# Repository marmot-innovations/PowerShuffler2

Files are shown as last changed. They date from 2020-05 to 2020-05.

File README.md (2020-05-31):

# PowerShuffler2
Summary: PowerShuffler2 is an update and modification of PowerShuffler1 to handle dual battery charging by intelligently multiplexing between two outputs.

Theory of operation: In a battery stack with 99 lithium-ion cells in series, there might be more than 1 weak cells that limit the usability of the entire battery pack. Let's assume the 99 li-ion cells are arranged in groups of 9 and there are certain groups that contain cells which are stronger than others. PowerShuffler2 is a PCBA that will piggy-back on top of the existing BMS that comes with the battery pack and draw power from the stronger group in order to charge up the 1 or 2 weak cells wherever they sit in the series of 99 cells. PowerShuffler2 has built-in intelligence to select the lower of the two output cell voltages and to prevent over-discharging the stronger group by measuring the voltage of the weakest cell as it rises, and comparing it to 1/9th of the stronger group's total voltage as it falls to within a certain threshold. Pre-programmed hysteresis and voltage-read-before-charging prevents excessive start-stop charging as the cells are put through normal usage during the time when the existing BMS kicks in. Although intrusive, PowerShuffler2 is meant to be a diagnostics tool to verify and characterize weak cells within a battery stack on top of a pre-existing BMS. It does not replace the need for servicing the battery pack or using a better BMS down the road. PowerShuffler2 has no wired or wireless communication, which is not accessible anyway if piggy-backed within a battery pack enclosure.

Included in this project are:
1. Firmware for client MCU
2. PCB design for PCBA

Not included in this project is:
1. Firmware for master MCU (see PowerShuffler1 project)

Read the individual README for further details. Pictures will be added later to provide instructions for programming and installation, as well as board modifications where needed. Test data will be provided eventually.

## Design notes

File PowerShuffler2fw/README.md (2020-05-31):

These projects were created and compiled in Microchip's Atmel Studio 7.0.2397  
For the ATTINY10 SOT-23-6 microcontroller

See PowerShuffler1 project for master MCU firmware.

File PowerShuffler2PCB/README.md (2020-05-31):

## PowerShuffler 2.0 PCB design schematic, layout, Gerbers, and BOM  
KiCAD 5.0.0 for PCB design  
Microsoft Excel web for BOM  
No 3D model  
No XY pick and place Centroid  
No ODB++  
No footprint library  
No schematic library

Design bugs and comments:  
1. To program master MCU, remove R6 and C7 first, then replace them once programming is completed. These components will put too much load on ISP TPI programmer.
2. To program client MCU, remove C24 and R22 first, then replace them once completed. These components will put too much load on ISP TPI programmer.
3. J2 and J4 do not need soldered headers for programming. Just shove a 5-pin 0.1" straight strip header into it to establish electrical contact. Look up "sneaky footprints PCB" on the web.
4. Mounting holes are for 4-40 screws and stand-offs.
5. Peak 82% efficiency during max charge rate as measured.
6. Less than 0.5mA current draw from input when idle, not charging.
7. There is no D2 LED, only D1 and D3.

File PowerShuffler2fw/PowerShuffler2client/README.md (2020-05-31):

## PowerShuffler2 Client Firmware  
Microchip (Atmel) ATTINY10 8MHZ  
Operational VCC 3.3V  
Programming VCC 5.0V  
Reset line voltage 12V  
TPI programming interface  
Programmer AVR ISP mk2

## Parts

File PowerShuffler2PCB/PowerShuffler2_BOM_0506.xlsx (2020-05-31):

ref | quantity | qty x 3 | value | Mouser P/N | Manufacturer P/N | description | footprint
C12, C14, C16, C19, C2, C26, C30, C6, C9 | 9 | 27 | 0.1u | 791-1206B104K101CT | 1206B104K101CT | Unpolarized capacitor | Capacitors_SMD:C_1206
C10 | 1 | 3 | 0.22u |  | CL31B224KBFNNNE | Unpolarized capacitor | Capacitors_SMD:C_1206
R16, R23 | 2 | 6 | 1.33M | 667-ERJ-8ENF1334V | ERJ-8ENF1334V | Resistor 1% | Resistors_SMD:R_1206
C20, C25 | 2 | 6 | 10u | 963-LMK316B7106KL-T | LMK316B7106KL-T | Unpolarized capacitor 10V | Capacitors_SMD:C_1206
C4 | 1 | 3 | 10u |  | CL31B106KBHNNNE | Unpolarized capacitor 50V | Capacitors_SMD:C_1206
R5 | 1 | 3 | 158k |  | RMCF1206FT158K | Resistor 1% | Resistors_SMD:R_1206
C1, C3, C5 | 3 | 9 | 1u |  | CL31B105KCHNNNE | Unpolarized capacitor 100V | Capacitors_SMD:C_1206
C11, C13, C15, C18, C21, C22, C24, C29, C7, C8 | 10 | 30 | 1u | 791-MT31B105K500CT | MT31B105K500CT | Unpolarized capacitor 50V | Capacitors_SMD:C_1206
C17, C23 | 2 | 6 | 4.7u | 80-C1206C475K4P7210 | C1206C475K4PAC7210 | Unpolarized capacitor | Capacitors_SMD:C_1206
C27, C28 | 2 | 6 | 15u | 80-T491X226K50ATAUTO | T491X226K050ATAUTO | Unpolarized capacitor 50V | BMB:2917
R1, R10, R24 | 3 | 9 | 191k | 667-ERJ-8ENF1913V | ERJ-8ENF1913V | Resistor 1% | Resistors_SMD:R_1206
R11, R12, R18, R8 | 4 | 12 | 2k | 652-CR1206FX-2001ELF | CR1206-FX-2001ELF | Resistor 1% | Resistors_SMD:R_1206
R13, R19, R22, R25, R6 | 5 | 15 | 390 | 652-CR1206FX-3900ELF | CR1206-FX-3900ELF | Resistor 1% | Resistors_SMD:R_1206
R14, R17 | 2 | 6 | 820 | 660-RK73B2BTTE821J | RK73B2BTTE821J | Resistor 5% | Resistors_SMD:R_1206
R15 | 1 | 3 | 200k | 667-ERJ-8ENF2003V | ERJ-8ENF2003V | Resistor 1% | Resistors_SMD:R_1206
R3 | 1 | 3 | 210k |  | ERA-8AEB2103V | Resistor 0.1% | Resistors_SMD:R_1206
R4 | 1 | 3 | 18.7k |  | ERA-8AEB1872V | Resistor 0.1% | Resistors_SMD:R_1206
R7 | 1 | 3 | 470 |  | RMCF1206JT470R | Resistor 5% | Resistors_SMD:R_1206
R2 | 1 | 3 | 49.9k |  | RMCF1206FT49K9 | Resistor 1% | Resistors_SMD:R_1206
R20, R21 | 2 | 6 | 5.6k | 652-CR1206FX-5601ELF | CR1206-FX-5601ELF | Resistor 1% | Resistors_SMD:R_1206
R9 | 1 | 3 | 22.1 |  | RMCF1206FT22R1 | Resistor 1% | Resistors_SMD:R_1206
L1 | 1 | 3 | 680u | 810-VLS6045EX-681M | VLS6045EX-681M | Inductor | BMB:SMD_Inductor_Shielded_6x6mm
U1, U8 | 2 | 6 | MCP6401 | 579-MCP6401T-H/OTVAO | MCP6401T-H/OTVAO | Precision Micropower, Low Noise CMOS, Rail-to-Rail Input/Output Operational Amplifier, TSOT-23-5 | TO_SOT_Packages_SMD:SOT-23-5_HandSoldering
U10 | 1 | 3 | 74AHC1G14 | 771-74AHC1G14GW-G | 74AHC1G14GW,125 | Single Schmitt NOT Gate, Low-Voltage CMOS | TO_SOT_Packages_SMD:SOT-353_SC-70-5_Handsoldering
U11 | 1 | 3 | SN74LVC2G08 | 595-SN74LVC2G08DCUR | SN74LVC2G08DCUR |  | BMB:VSSOP-8
U2 | 1 | 3 | SWITCHDCDCLOPOW | 700-MAX17550AUB+ | MAX17550AUB+ |  | BMB:10-μMAX_3x3mm
U3, U7 | 2 | 6 | ATTINY | 556-ATTINY10-TSHR | ATTINY10-TSHR |  | TO_SOT_Packages_SMD:SOT-23-6_Handsoldering
U4 | 1 | 3 | SPBW03G | 709-SPBW03G-05 | SPBW03G-05 |  | BMB:SPBW03G
U5 | 1 | 3 | MCP73831 | 579-MCP73831T-3ACIOT | MCP73831T-3ACI/OT | 4.35V Li-Ion 500mA charger SOT-23-5 | TO_SOT_Packages_SMD:SOT-23-5_HandSoldering
U6 | 1 | 3 | LT3009 | 584-LT3009ESC8TRMPBF | LT3009ESC8#TRMPBF |  | TO_SOT_Packages_SMD:SC-70-8_Handsoldering
U9 | 1 | 3 | 74AUC1G79 | 771-74AHC1G79GW-G | 74AHC1G79GW,125 | Single D Flip-Flop, Low-Voltage CMOS | TO_SOT_Packages_SMD:SOT-353_SC-70-5_Handsoldering
J3, J5 | 2 | 6 | Conn_01x02 | 538-43650-0200 | 43650-0200 |  | BMB:Molex_Microfit3_Header_2pin_Angled_43650
J1 | 1 | 3 | Conn_01x03 | 538-43650-0301 | 43650-0301 |  | BMB:Molex_Microfit3_Header_3pin_Angled_43650
J2, J4 | 2 | 6 | Conn_01x05 | N/A | N/A | staggered 0.1" spaced hole programming port | BMB:Staggered_ICSP_5x2.54mm_Straight
F1 | 1 | 3 | Fuse | 576-0468002.NRHF | 0468002.NR | Surface Mount Fuses 1206 SLO-BLO 2A SLIMLINE HALIDE FREE | Fuse_Holders_and_Fuses:Fuse_SMD1206_HandSoldering
F2, F3 | 2 | 6 | Fuse | 650-1206SFP200F/63-2 | 1206SFP200F/63-2 | Surface Mount Fuses VERY FAST GLASS CER 63V 2A SZ 1206 | Fuse_Holders_and_Fuses:Fuse_SMD1206_HandSoldering
D1 | 1 | 3 | LED | 710-150120GS75000 | 150120GS75000 | Green LED 1206 | LEDs:LED_1206
D3 | 1 | 3 | LED | 710-150120RS75000 | 150120RS75000 | Red LED 1206 | LEDs:LED_1206
S1 | 1 | 3 | SSR4 | 849-CPC1002N | CPC1002N | Solid State Relays - PCB Mount 1-Form-A 60V 700mA Solid State Relay MOSFET w/ intrinsic diode | BMB:SMD4_SSR_CPC1002N
S2 | 1 | 3 | OPTOSOLO | 859-LTV-816S | LTV-816S | Transistor Output Optocouplers Optocoupler Phototrans PDIP-4 Gull Wing | BMB:SMD4_TL241AF-SSR_0.1_12x5mm
S3 | 1 | 3 | SSR4 | 782-VO1400AEFTR | VO1400AEFTR | Solid State Relays - PCB Mount Normally Open Form 1A SOP-4 100mA load very low leakage current | BMB:SMD4_SSR_CPC1002N
S4, S5, S6, S7 | 4 | 12 | SSR4 | 876-SMP-1A47-4PT | SMP-1A47-4PT | Solid State Relays - PCB Mount 1 Form A 80V 1.25A SOP-4 that does not have MOSFET intrinsic diode

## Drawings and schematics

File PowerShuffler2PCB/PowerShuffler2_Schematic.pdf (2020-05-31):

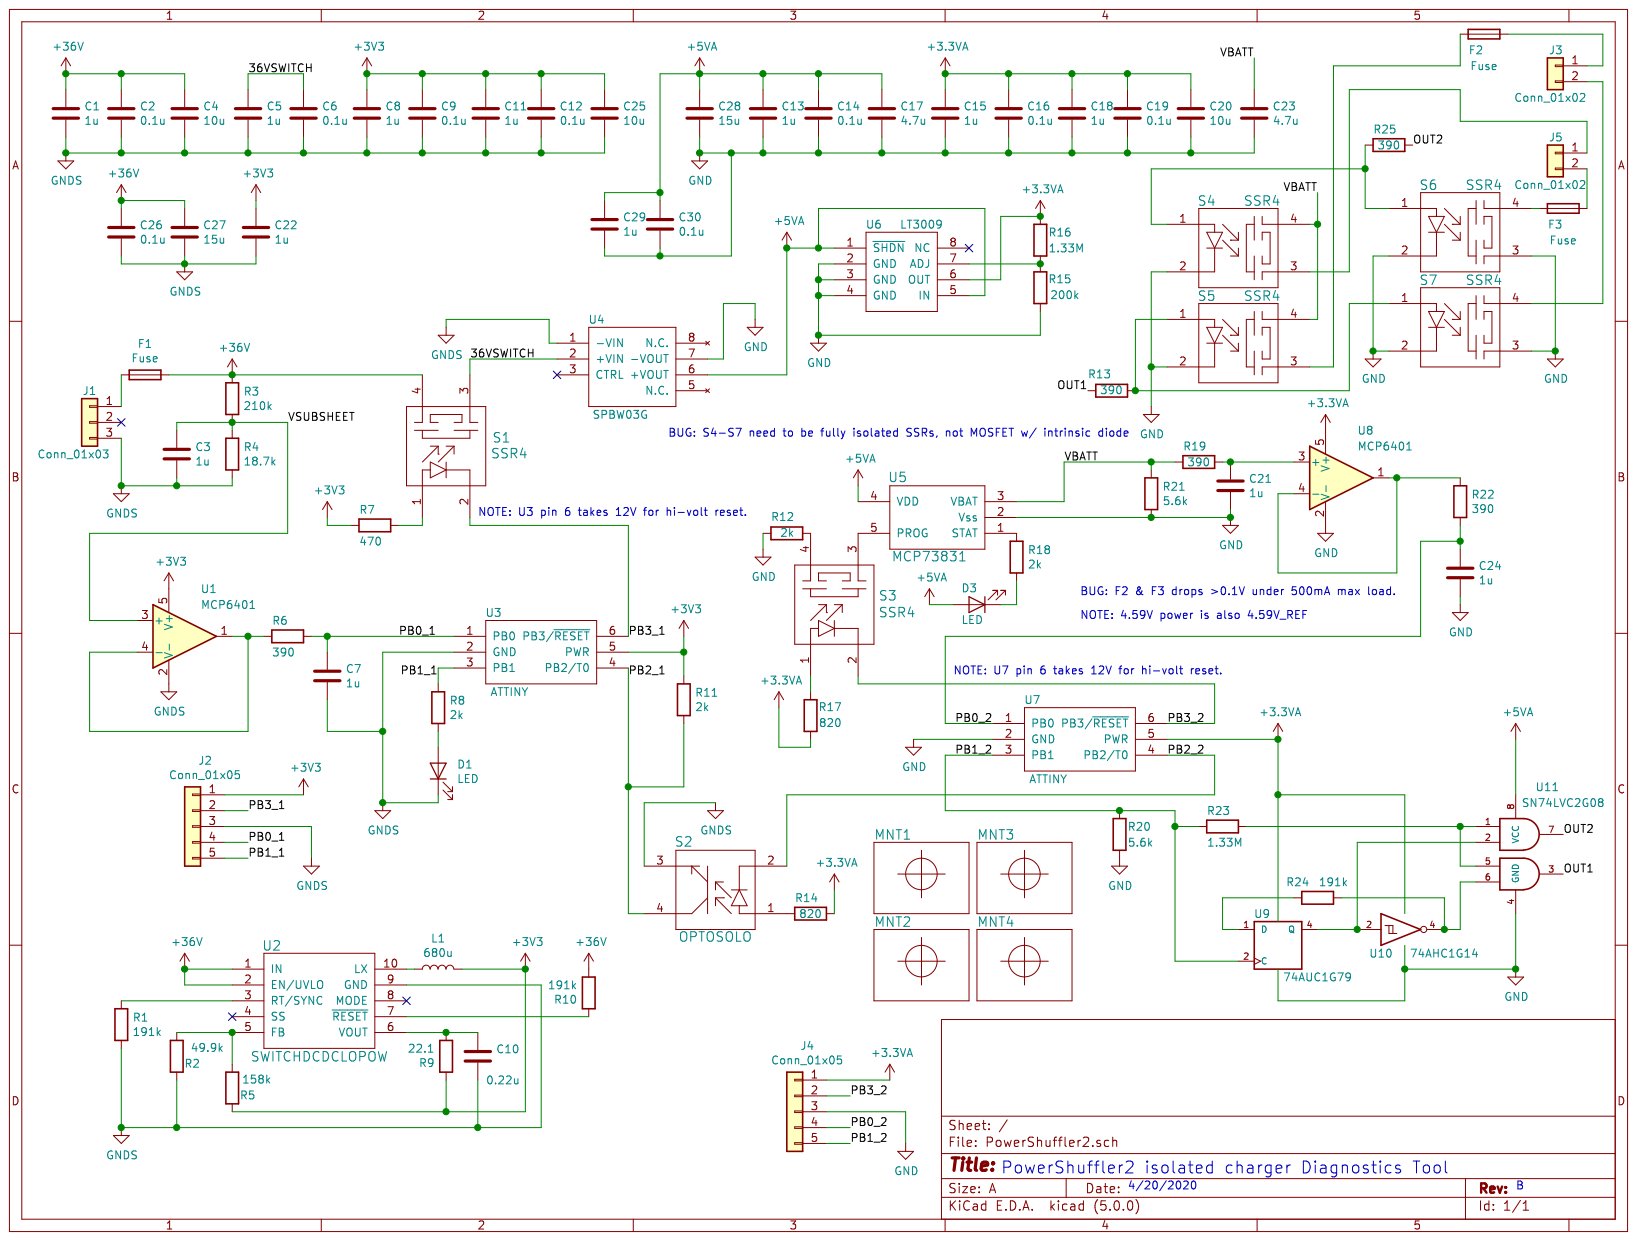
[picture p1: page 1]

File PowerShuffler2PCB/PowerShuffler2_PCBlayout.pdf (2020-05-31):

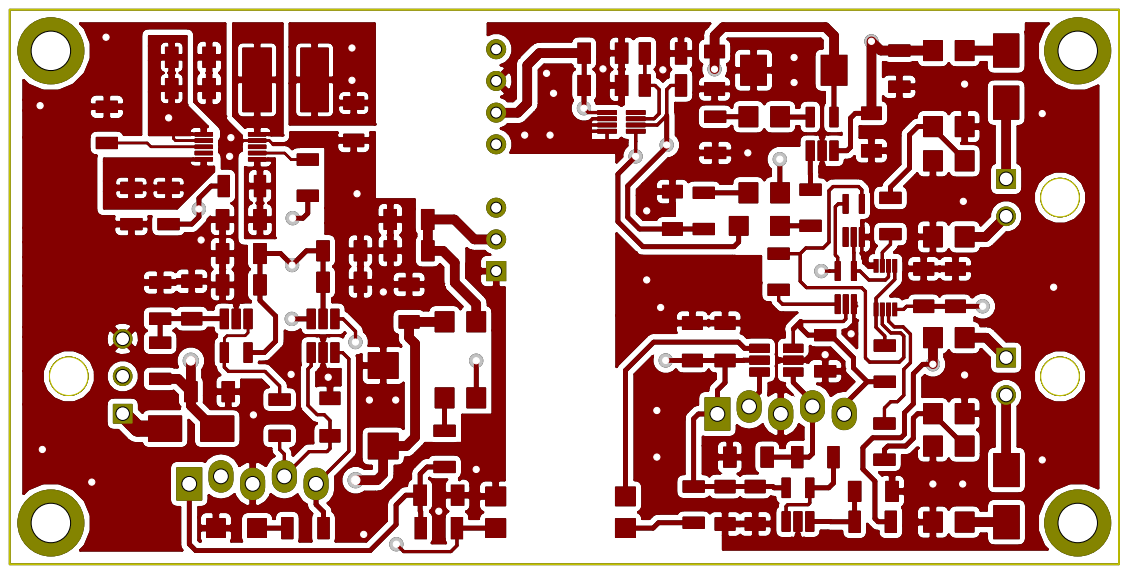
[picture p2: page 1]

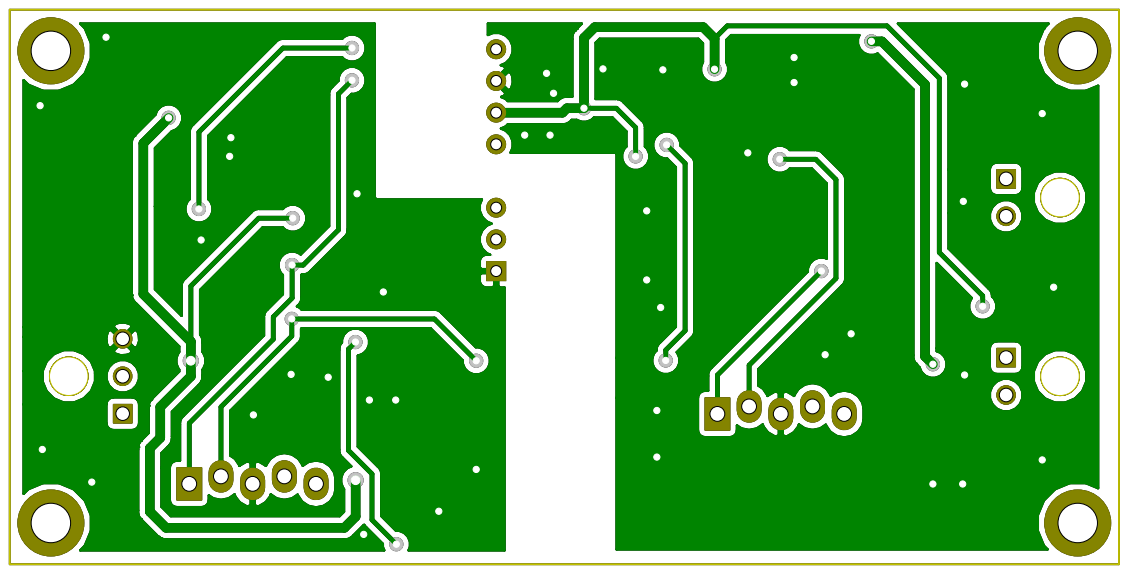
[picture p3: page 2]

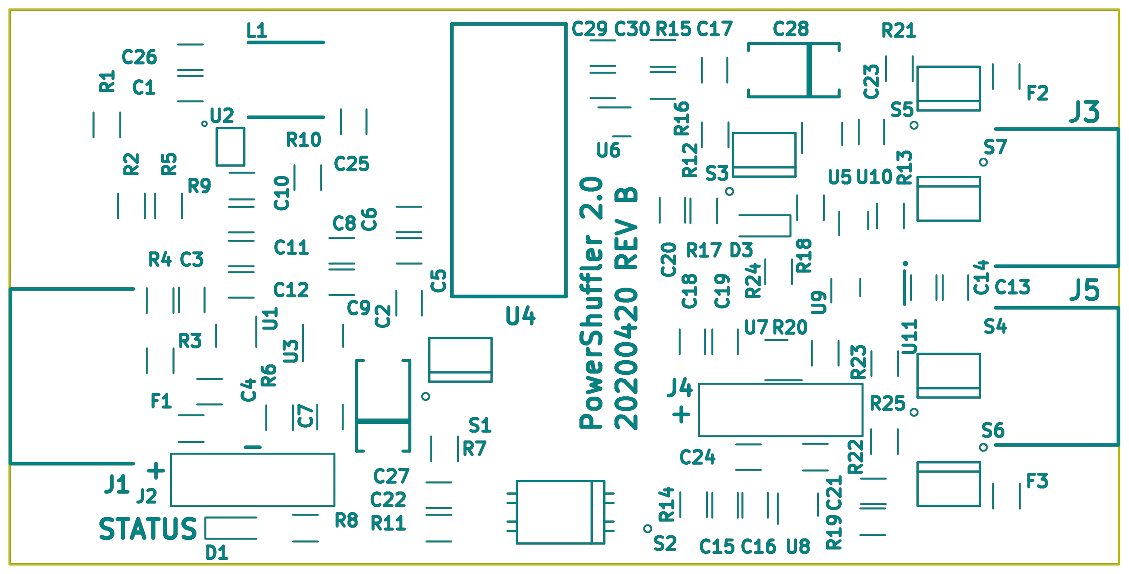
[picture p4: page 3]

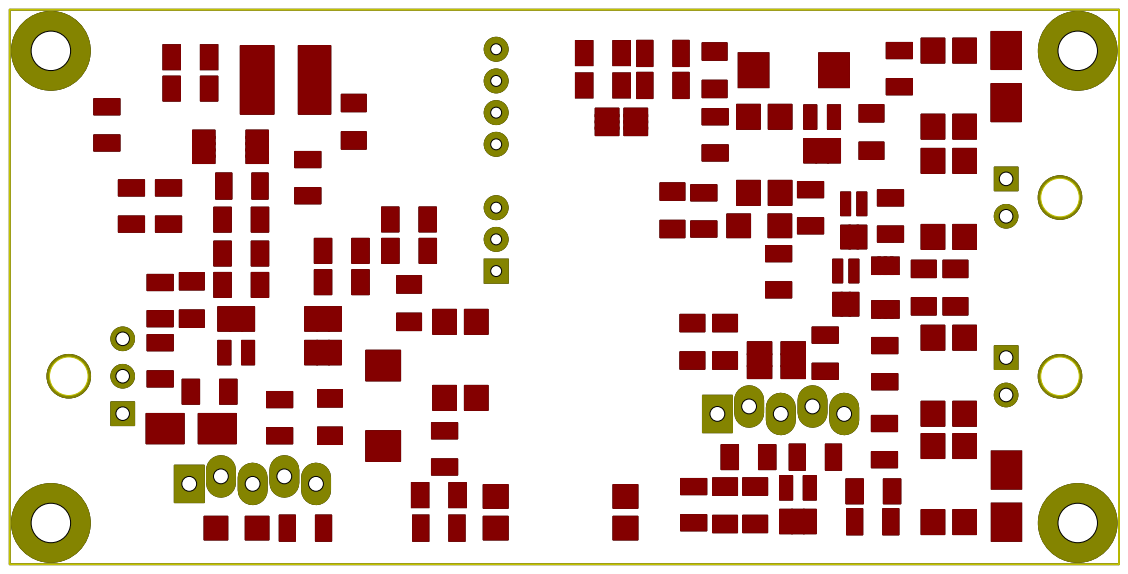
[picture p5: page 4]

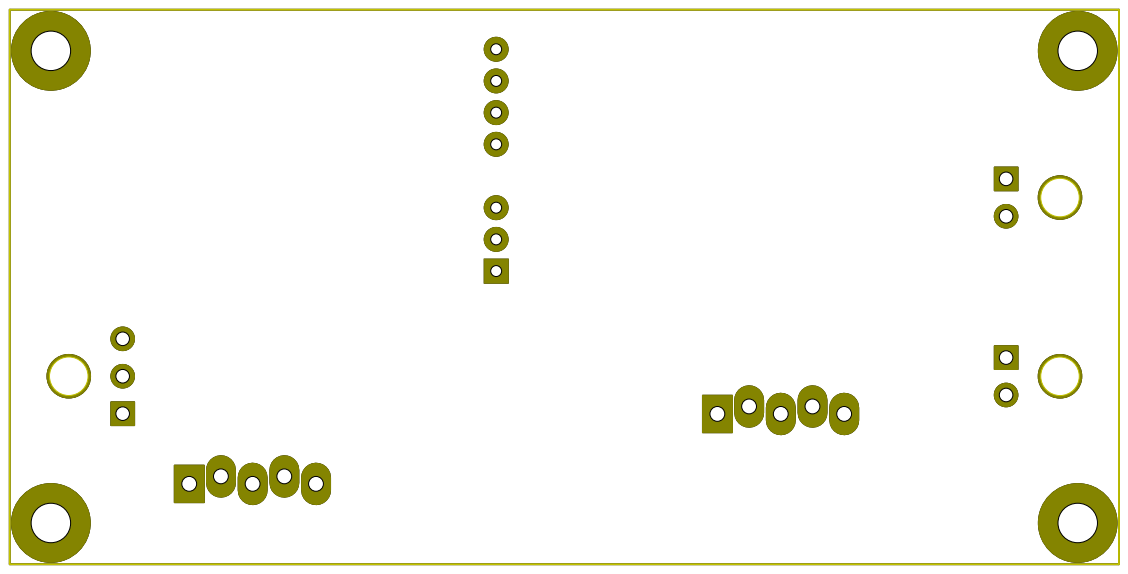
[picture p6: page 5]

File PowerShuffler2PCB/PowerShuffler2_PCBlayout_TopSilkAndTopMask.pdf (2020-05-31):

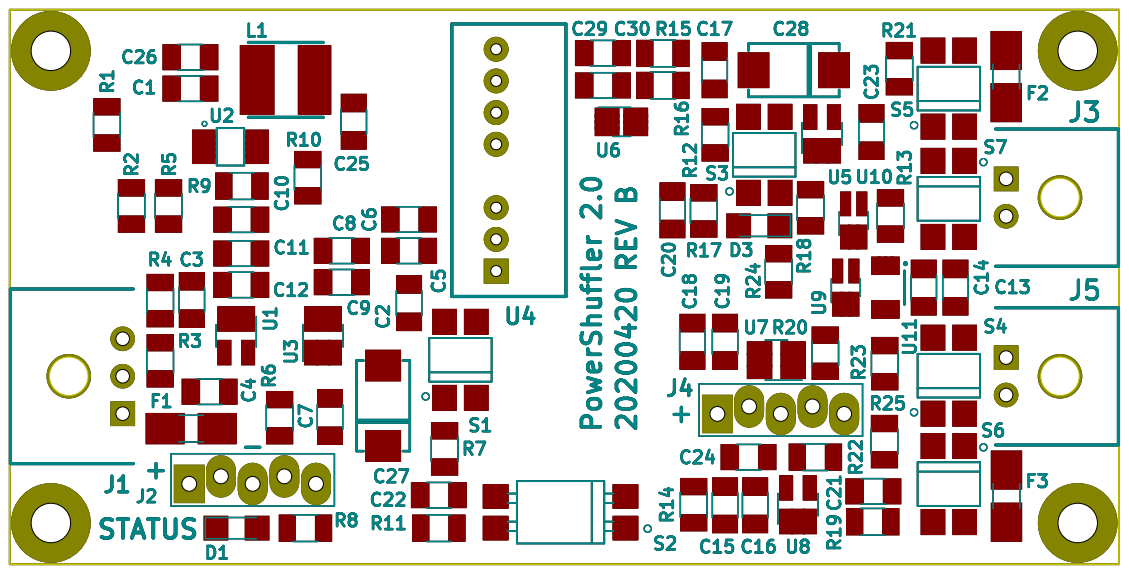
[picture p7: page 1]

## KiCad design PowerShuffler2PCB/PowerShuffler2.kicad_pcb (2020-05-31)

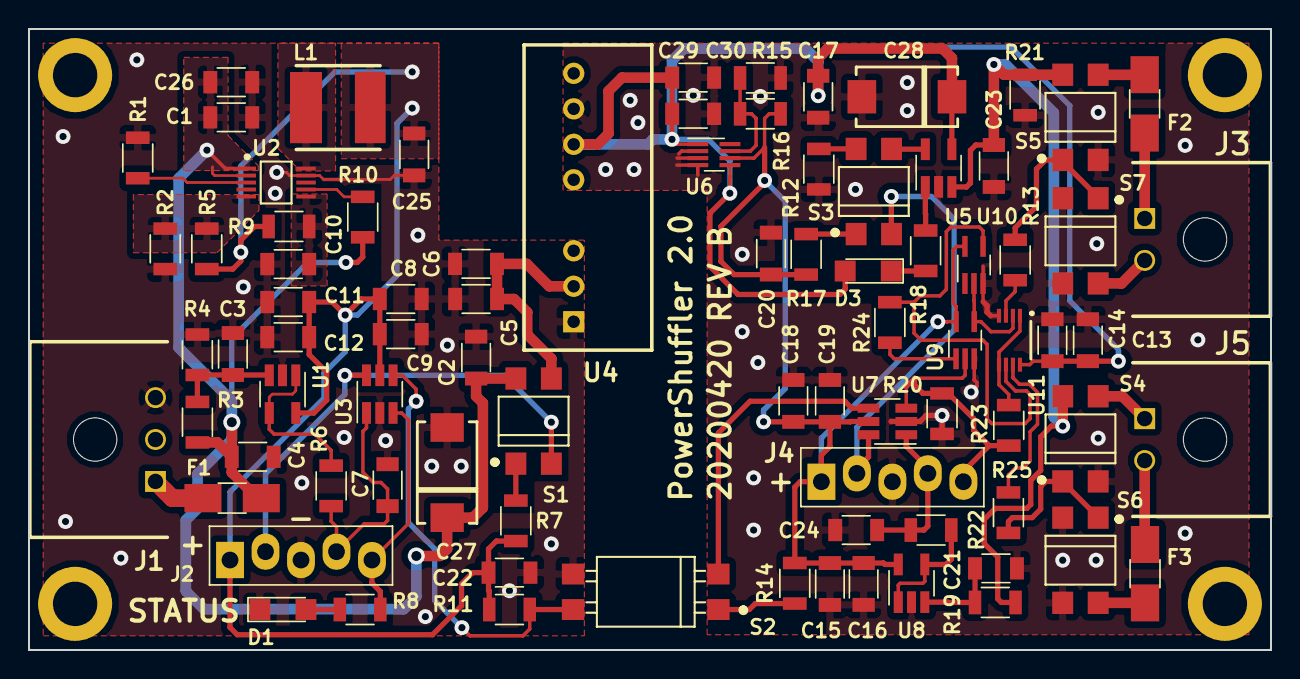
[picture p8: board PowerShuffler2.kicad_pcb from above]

Board: 4 copper layers, 88.9 x 44.5 mm, 88 parts (0 on the bottom side), 49 nets.

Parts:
C1, C3, C5, C7, C8, C11, C13, C15, C18, C21, C22, C24, C29: 1u; C_1206
C2, C6, C9, C12, C14, C16, C19, C26, C30: 0.1u; C_1206
C4, C20, C25: 10u; C_1206
C10: 0.22u; C_1206
C17, C23: 4.7u; C_1206
C27, C28: 15u; 2917
D1, D3: LED; LED_1206
F1, F2, F3: Fuse; Fuse_SMD1206_HandSoldering
J1: Conn_01x03; Molex_Microfit3_Header_3pin_Angled_43650
J2, J4: Conn_01x05; Staggered_ICSP_5x2.54mm_Straight
J3, J5: Conn_01x02; Molex_Microfit3_Header_2pin_Angled_43650
L1: 680u; SMD_Inductor_Shielded_6x6mm
MNT1, MNT2, MNT3, MNT4: MountingHole; 3mm_hole
R1, R10, R21, R24: 191k; R_1206
R2: 49.9k; R_1206
R3: 210k; R_1206
R4: 19.1k; R_1206
R5: 158k; R_1206
R6, R13, R19, R22, R25: 390; R_1206
R7: 470; R_1206
R8, R11, R12, R18: 2k; R_1206
R9: 22.1; R_1206
R14, R17: 820; R_1206
R15: 200k; R_1206
R16, R23: 1.33M; R_1206
R20: 5.6k; R_1206
S1, S3, S4, S5, S6, S7: SSR4; SMD4_SSR_CPC1002N
S2: OPTOSOLO; SMD4_TL241AF-SSR_0.1_12x5mm
U1, U8: MCP6401; SOT-23-5_HandSoldering
U2: SWITCHDCDCLOPOW; 10-μMAX_3x3mm
U3, U7: ATTINY; SOT-23-6_Handsoldering
U4: SPBW03G
U5: MCP73831; SOT-23-5_HandSoldering
U6: LT3009; SC-70-8_Handsoldering
U9: 74AUC1G79; SOT-353_SC-70-5_Handsoldering
U10: 74AHC1G14; SOT-353_SC-70-5_Handsoldering
U11: SN74LVC2G08; VSSOP-8

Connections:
+3.3VA: C15.1, C16.1, C18.1, C19.1, C20.1, J4.1, R14.1, R16.1, R17.1, U6.6, U7.5, U8.5, U9.5, U10.5
+3V3: C8.1, C9.1, C11.1, C12.1, C22.1, C25.1, J2.1, L1.2, R5.1, R7.2, R9.1, R11.1, U1.5, U3.5
+5VA: C13.1, C14.1, C17.1, C28.1, C29.1, C30.1, D3.2, U4.6, U5.4, U6.1, U6.5, U11.8
+36V: C1.1, C2.1, C4.1, C26.1, C27.1, F1.1, R3.1, R10.2, S1.4, U2.1, U2.2
/36VSWITCH: C5.1, C6.1, S1.3, U4.2
/OUT1: R13.1, U11.3
/OUT2: R25.1, U11.7
/PB0_1: C7.1, J2.4, R6.1, U3.1
/PB0_2: C24.1, J4.4, R22.2, U7.1
/PB1_1: J2.5, R8.1, U3.3
/PB1_2: J4.5, R20.1, R23.2, U7.3, U9.2
/PB2_1: R11.2, S2.4, U3.4
/PB2_2: S2.2, U7.4
/PB3_1: J2.2, S1.2, U3.6
/PB3_2: J4.2, S3.2, U7.6
/VBATT: C23.1, R19.2, R21.1, S4.4, S5.4, U5.3
/VSUBSHEET: C3.1, R3.2, R4.1, U1.3
GND: C13.2, C14.2, C15.2, C16.2, C17.2, C18.2, C19.2, C20.2, C21.2, C23.2, C24.2, C28.2, C29.2, C30.2, J4.3, R12.1, R15.1, R20.2, R21.2, S4.2, S5.2, S6.2, S6.3, S7.2, S7.3, U4.7, U5.2, U6.2, U6.3, U6.4, U7.2, U8.2, U9.3, U10.3, U11.4
GNDS: C1.2, C2.2, C3.2, C4.2, C5.2, C6.2, C7.2, C8.2, C9.2, C10.2, C11.2, C12.2, C22.2, C25.2, C26.2, C27.2, D1.1, J1.3, J2.3, R1.2, R2.1, R4.2, S2.3, U1.2, U2.9, U3.2, U4.1
unnamed: C10.1, R9.2, U2.6
unnamed: C21.1, R19.1, U8.3
unnamed: D1.2, R8.2
unnamed: D3.1, R18.2
unnamed: F1.2, J1.1
unnamed: F2.1, J3.1
unnamed: F2.2, S5.3
unnamed: F3.1, J5.2
unnamed: F3.2, S6.4
unnamed: J3.2, S7.4
unnamed: J5.1, S4.3
unnamed: L1.1, U2.10
unnamed: R1.1, U2.3
unnamed: R2.2, R5.2, U2.5
unnamed: R6.2, U1.1, U1.4
unnamed: R7.1, S1.1
unnamed: R10.1, U2.7
unnamed: R12.2, S3.4
unnamed: R13.2, S5.1, S7.1
unnamed: R14.2, S2.1
unnamed: R15.2, R16.2, U6.7
unnamed: R17.2, S3.1
unnamed: R18.1, U5.1
unnamed: R22.1, U8.1, U8.4
unnamed: R23.1, U11.1, U11.5
unnamed: R24.1, U10.4, U11.6
unnamed: R24.2, U9.1
unnamed: R25.2, S4.1, S6.1
unnamed: S3.3, U5.5
unnamed: U9.4, U10.2, U11.2

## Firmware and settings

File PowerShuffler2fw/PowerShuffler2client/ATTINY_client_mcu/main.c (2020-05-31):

/*
 * ATTINY_client_mcu.c
 *
 * Created: 5/14/2020 2:09:01 PM
 * Author : mike
 * Summary: This client MCU code as-is is designed to run on one or two 4.2V single cell Li-ion battery.
 *          The algorithm will determine which ports are connected to a battery, select the lowest voltage,
 *          take the voltage reading, turn on the charger, take the second voltage reading, then report the
 *          measured voltage minus the difference to the master MCU. Every few minutes it will stop the
 *          charger to re-check OCV of the batteries. If the voltage difference between two output ports are
 *          close, the timeout to re-check OCV will be cut in half.
 */

#define F_CPU 8000000UL // 8 MHz
#define TRIGGERTIMEOUTUS     255   // minimum delay in microseconds to trigger master MCU reading
#define TRANSMITDELAYUS      32    // delay in microseconds between transmitting edges (1 bit = 1 falling and 1 rising edge)
#define POWERDEBOUNCEDELAYMS 500   // power-on debounce delay must be less than 4 seconds due to watchdog timeout
#define ADCITERATIONS        4     // Number of readings to take an average
#define ADCREADDELAYMS       10    // Delay between ADC readings
#define MAXVOLTAGEADCVALUE   232   // ADC value of maximum battery voltage (about 4.19V battery)
#define MUXONDEBOUNCEDELAYMS 125   // Delay after switching on Battery Mux
#define RECHECKVOLTAGECOUNT  66    // Number of iterations before re-checking voltages (roughly 5min with a stopwatch)
#define RECHECKVOLTAGEFAST   RECHECKVOLTAGECOUNT/2 // Recheck voltages faster when two output voltages are very close to each other
#define CHARGERDEBOUNCEDELAYMS 500 // charger turn-on debounce delay
#define MUXOFFDEBOUNCEDELAYMS  500 // Delay after switching off Battery Mux
#define WAITFORMASTERDELAYMS 750   // Wait for master response delay before turning on charger (master takes about .5s to respond)
#define DISCHARGEWAITDELAYMS 250   // Wait for power lines to stabilize when charger turns off

#include <avr/io.h>
#include <util/delay.h>
#include <avr/interrupt.h>
#include <avr/sleep.h>
#include <avr/wdt.h>

void initializeRegisters()
{
	// Clock frequency
	CCP    = 0xD8; // write the signature to enable CPU changes per datasheet
	CLKPSR = 0x00; // 0000 0000 for prescaler 1
	
	// Watchdog timer and Sleep Mode
	WDTCSR = 0x60; // 0110 0000 Interrupt Mode and 512k prescalar (about 4 seconds)
	SMCR   = 0x05; // 0000 0101 Power-Down mode

	// Ports and pins
	// PB0 = ADC0 output battery voltage
	// PB1 = Battery MUX output (default lo)
	// PB2 = Data Output, hi idle (default hi)
	// PB3 = Charger Disable (default hi disables charger)
	// PUEB  |= _BV(0); // for debugging, enable pull-up on ADC0
	PUEB  |= _BV(3); // enable pull-up on PB3 (charger disable)
	PORTB |= _BV(2); // ensure output PB2 is hi (not transmitting / idle)
	DDRB  |= _BV(1); // 0000 0010 for Battery MUX output pin PB1
	DDRB  |= _BV(2); // 0000 0100 for Data Output pin PB2
	// DDRB  |= _BV(3); // 0000 1000 for Charger Disable output pin PB3

	_delay_ms(POWERDEBOUNCEDELAYMS); // power-on debounce
	wdt_reset();

	// ADC
	ADCSRA = 0x83; // 1000 0011 enables ADC and set prescaler 8
	// ADCSRB = 0x00; // Single Conversion Mode
	// ADMUX = 0x00; // Select ADC0 on PB0
	DIDR0 = 0x0E; // 0000 1110 disables buffers on unused ADC pins for power savings

	// Interrupts
	SREG = 0x80; // 1000 0000 to globally enable interrupts
}

unsigned short isMuxOn() // return 0 if mux is off
{
	return (PORTB & _BV(1));
}

void turnOnMux()
{
	if(isMuxOn()) return;
	PORTB |= _BV(1); // 0000 0010 set PB1
	_delay_ms(MUXONDEBOUNCEDELAYMS); // wait for steady-state
}

void turnOffMux()
{
	if(!isMuxOn()) return;
	PORTB &= ~_BV(1); // 1111 1101 clear PB1
	_delay_ms(MUXOFFDEBOUNCEDELAYMS); // wait for full disconnect
}

void toggleMux()
{
	turnOffMux();
	turnOnMux();
}

unsigned short isChargerOn() // return 0 if charger is off
{
	return (DDRB & _BV(3));
}

void turnOnCharger()
{
	if(isChargerOn()) return;
	PUEB &= ~_BV(3); // Disable pull-up resistor to save power
	DDRB |= _BV(3);  // Enable output pin PB3 to lo
	_delay_ms(CHARGERDEBOUNCEDELAYMS);
}

void turnOffCharger()
{
	if(!isChargerOn()) return;
	PUEB |= _BV(3);  // Enable pull-up resistor to fully float PB3 hi
	DDRB &= ~_BV(3); // Set PB3 to float hi to turn off client.
	_delay_ms(DISCHARGEWAITDELAYMS);
}

void startADC()
{
	ADCSRA |= 0x40; // 0100 0000 set ADSC to start single conversion mode
}

unsigned short adcInProgress()
{
	return ADCSRA & 0x40; // 0100 0000 returns 0 if adc is done, non-zero otherwise.
}

unsigned short adcValue()
{
	// 0   = 0.0V
	// 255 = 4.6V as measured
	// Each step is 0.01804V
	return (unsigned short)ADCL;
}

unsigned short getAdcValueBusyWait()
{
	startADC();
	while(adcInProgress()); // busy waits until ADC conversion is done
	return adcValue();
}

void transmitOneTick()
{
	PORTB &= ~_BV(2);
	_delay_us(TRANSMITDELAYUS);
	PORTB |= _BV(2);
	_delay_us(TRANSMITDELAYUS);
}

void triggerRead()
{
	PORTB &= ~_BV(2);
	_delay_us(TRIGGERTIMEOUTUS); // hold lo for minimum trigger count
	PORTB |= _BV(2);
	_delay_us(TRANSMITDELAYUS);
}

void outputDataError() // holds the output lo for duration of power-on
{
	PORTB &= ~_BV(2);
}

unsigned int getAdcValueBusyWaitWithAveraging()
{
	unsigned int adcvalue = 0;
	for(int i=0; i<ADCITERATIONS; i++)
	{
		if(i) _delay_ms(ADCREADDELAYMS); // Skip delaying the first reading, then delay in milliseconds
		adcvalue += (unsigned int)getAdcValueBusyWait();
	}

	return adcvalue / ADCITERATIONS; // average ADC value
}

short transmitValue(unsigned int adcvalue) // return 0 if success, 1 if error.
{
	if(adcvalue >= MAXVOLTAGEADCVALUE || adcvalue == 0) // Over-voltage or grounded ADC input, although unlikely to be grounded during operation
	{
		outputDataError();
		return 1;
	}
	else
	{
		triggerRead(); // trigger the master MCU to start reading
		for(unsigned int j=0; j < adcvalue; j++)
		{
			transmitOneTick(); // transmit 1 bit at a time
		}
	}
	return 0;
}

ISR(WDT_vect)
{
	// do nothing and wake up MCU
}

// LED status behavior and description: There are no LED for this client MCU
int main(void)
{
	// variables used to select battery, calculate offset, and store voltage values
	int adcFloatingValue, adcInitialValue0, adcInitialValue1, adcvalue, recheckMaxCount;
	initializeRegisters(); // includes a sleep delay for power-on debounce

	while(1)
	{
		wdt_reset();
		turnOnMux();
		adcInitialValue0 = getAdcValueBusyWait();  // get first (or currently selected) battery voltage
		turnOffMux();
		adcFloatingValue = getAdcValueBusyWait();  // get floating voltage (should be 0)
		turnOnMux();                               // toggle mux without waiting for turn-off delay
		adcInitialValue1 = getAdcValueBusyWait();  // get second battery voltage
		if(adcInitialValue1 <= adcFloatingValue || // toggle mux if second battery voltage is floating
		   (adcInitialValue0 < adcInitialValue1 && // or if first voltage is lower than second
		    adcInitialValue0 > adcFloatingValue))  //       and not floating
		{
			toggleMux();
		}

		// Get the voltage difference between inputs and adjust recheck max count. Smaller voltage difference, faster timeout.
		recheckMaxCount = adcInitialValue0 - adcInitialValue1;
		recheckMaxCount = (recheckMaxCount > 1 || recheckMaxCount < -1) ? RECHECKVOLTAGECOUNT : RECHECKVOLTAGEFAST;

		adcInitialValue0 = getAdcValueBusyWaitWithAveraging(); // Get more accurate OCV of selected battery
		if(adcInitialValue0 >= MAXVOLTAGEADCVALUE || adcInitialValue0 == 0) // Over-voltage or grounded ADC input
		{
			outputDataError();
			continue; // skip the rest of the while-loop and start over
		}

		wdt_reset();
		transmitValue(adcInitialValue0);
		_delay_ms(WAITFORMASTERDELAYMS); // wait and see if master MCU decides to turn off client MCU based on OCV value.
		turnOnCharger();
		adcInitialValue0 = getAdcValueBusyWaitWithAveraging() - adcInitialValue0; // get voltage offset after charger has turned on

		for(int i=1; i <= recheckMaxCount; i++)
		{
			wdt_reset();
			adcvalue = getAdcValueBusyWaitWithAveraging() - adcInitialValue0; // subtract offset from ADC reading

			// exit the loop immediately upon error or on the last iteration due to communications timing constraints
			if(transmitValue(adcvalue) || i == recheckMaxCount) break;
			ADCSRA &= 0x7F; // disable ADC
			PRR = 0x03; // turn off ADC and timers to save power
			wdt_reset();
			sleep_mode();
			PRR = 0x00; // restore power
			ADCSRA |= 0x80; // enable ADC
		}
		turnOffCharger();
	}
}

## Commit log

2020-05-31 Add PCB design files and BOM
    [PowerShuffler2.kicad_pcb, PowerShuffler2.sch, PowerShuffler2_BOM_0506.xlsx]
2020-05-31 Add PCB Gerber and drill files
    [PowerShuffler2-B.Cu.gbl, PowerShuffler2-B.Mask.gbs, PowerShuffler2-Edge.Cuts.gm1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]
2020-05-31 Add AtmelStudio source files, client MCU fw
    PowerShuffler2
2020-05-31 Update README to locate master MCU fw
    master MCU fw is in PowerShuffler1
